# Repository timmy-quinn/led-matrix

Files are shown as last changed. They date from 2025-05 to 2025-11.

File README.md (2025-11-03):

# LED Matrix

A simple 8 by 8 LED matrix made from easy-to-find Neopixel LED strips, 
adhered to a laser-cut baseboard, and mounted in a 3D printed case. 

Control is provided by an ESP32 microcontroller. Code written in the 
Arduino IDE. Several demos can be found in [01_demos](01_demos).  

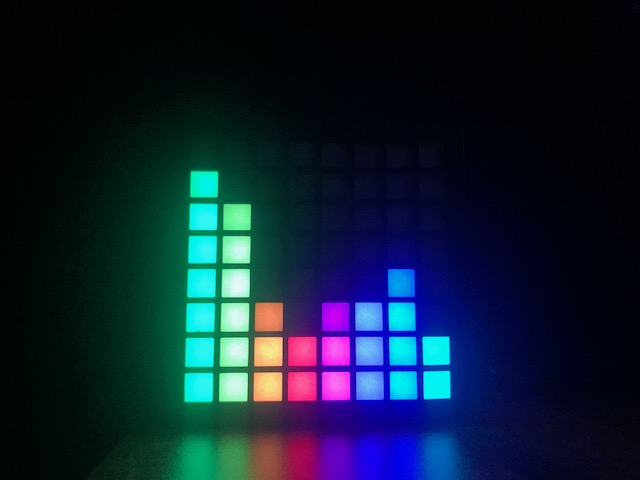
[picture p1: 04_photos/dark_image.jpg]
Music visualizer in the dark
  
*LED-matrix v1.0*

### Materials
- 1 x ESP32 Devkit V1
- 1 x MAX9814 Module
- 1 x WS2812 LED Strip (64 LEDs, 60 Pixel/meter)
- 1 x 1/16th inch wood board (at least 5"x5") 
- 8 x M2 heat-set threaded inserts
- 4 x M3 heat-set threaded inserts
- 4 x M2 x 4mm screws 
- 4 x M2 x 6mm screws
- 4 x M3 x 6mm screws
- 4 x 6mm x 2mm neodymium magnets 
- 1 x Parchment paper or other thin light diffuser
- 1 x 4cm x 6cm universal proto-board
- 1 x 5 pin 2.54mm female header 
- 2 x 20 pin 2.54mm female header
- 1 x JST Female Connector
- 1 x JST Male Connector
- 1 x USB-A to micro-USB type B cable (with data lines)
 
##### Additional requirements 
- 3D printer
- Soldering iron
- Solder
- Super glue
- Hot glue

### Assembly instructions
_More photos to come!_

1. Print the base, cover and back. STL files can be found in [02_mechanical](02_mechanical)
2. Using a soldering iron, insert the 4 M3 heat-set inserts into the outer 
threaded insert holes. Insert the 8 M2 heat-set inserts into the remaining 
holes.  
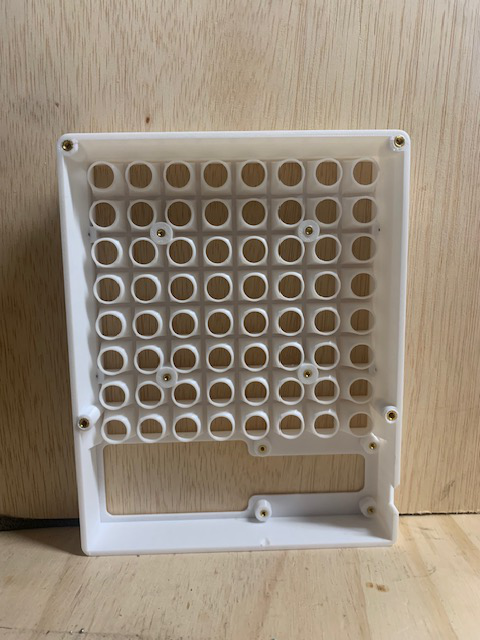
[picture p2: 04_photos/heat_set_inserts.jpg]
Heat set inserts
  
3. Cut out the LED board, with dimensions matching those in the CAD file, 
or use a laser cutter. 
4. Cut the LED strip into sections of 8, cutting down the center of the 
copper pads. 
5. Use the silicone wire to solder the individual LED strips. Make sure 
the wire is the length of the LED board, plus perhaps an extra inch. Make 
sure that the DOUT pad of each LED strip connects the DIN pad of the 
next strip. DO NOT connect a DIN pad to DIN, or a DOUT pad to DOUT.  
6. Attach the LEDs to the board, by removing the thin plastic backing and 
attaching them to the board, using the adhesive on the strip. Then use 
little touches of hot glue around the edges of the board, to prevent the 
LED strip from peeling off, and to cover the exposed wire and copper pads. 
7. To the last LED strip, solder on a JST connector. 
8. Screw the LED board to the 3-d printed base using M2 screws.   
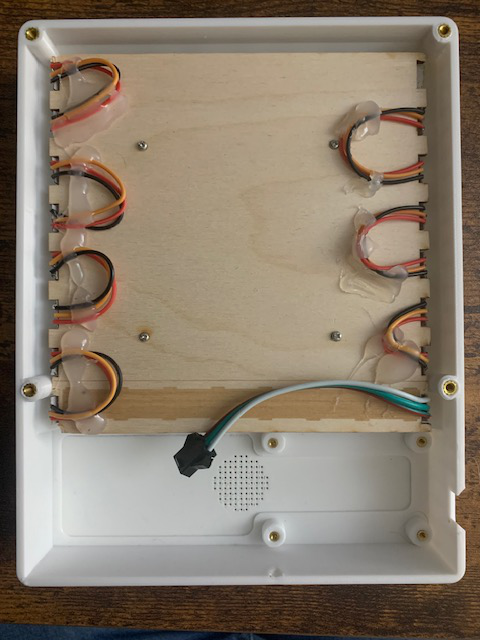
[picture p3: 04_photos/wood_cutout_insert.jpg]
Board attached to base

9. Solder 18 pin female header pins to the proto board. For the microphone, 
add a 5 pin female header pin.
10. Solder a JST connector to the proto-board. (Must be able to connect 
to the corresponding connector attached to the LED strip). Connect 5v to 
the ESP32 VIN pin. Connect ground to GND. Connect DIN to pin D13 (At least 
if you want to be consistent with the demo code. 
11. Solder connections for the MAX9814 header pin. Make sure that V+ is 
connected to the ESP32 3v3 pin, GND is connected to GND, and to be 
consistent with the demo code, connect Out to D32, G (gain) to D5, and AR 
to D22. 
12. Screw the proto-board to case. Insert the ESP32 board into the female 
header pins. Insert the MAX9814 to the corresponding header pins. 
13. Connect the JST connector from the proto board to the LED strips. 
14. Super glue magnets to the exterior of the case, and the interior of the cover.  
Ensure that the magnets are orientated such that when the cover is placed 
onto the case, the magnets attract each other and do not repel each other. 
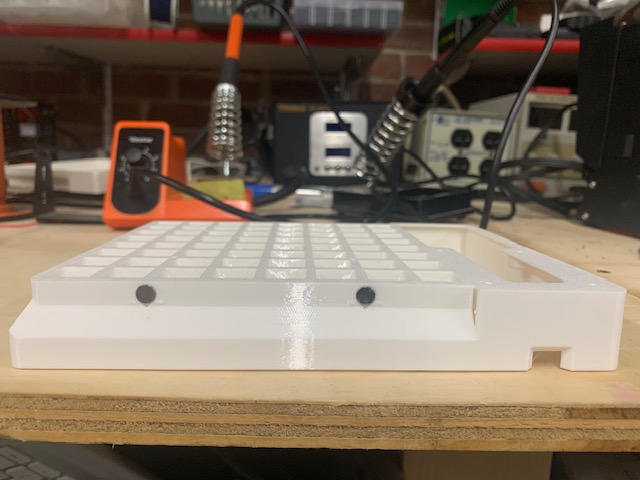
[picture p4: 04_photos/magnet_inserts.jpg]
Magnets inserted into exterior
  
15. Cut a strip of your parchment paper or other diffuser material, using 
the front of the base as a guide. You can leave a little room around the
edges to make sure that the diffuser material covers the entire grid case.   
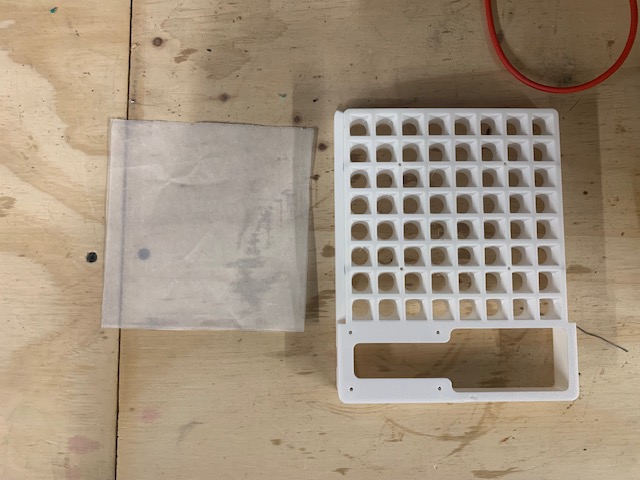
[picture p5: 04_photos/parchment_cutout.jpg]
Diffuser cutout
  
16. Place the diffuser on the base, then put the cover over it.  
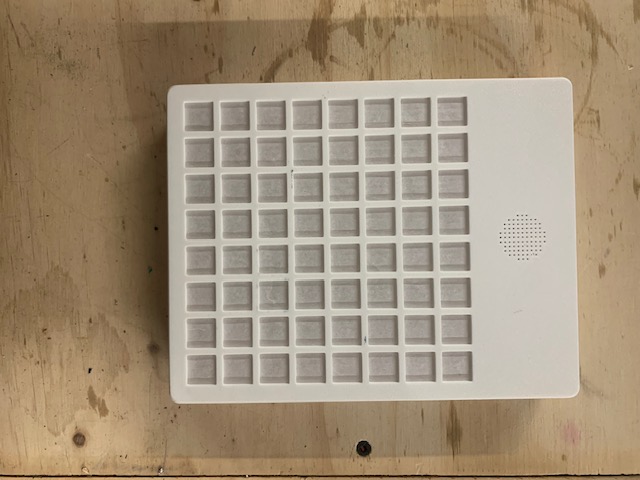
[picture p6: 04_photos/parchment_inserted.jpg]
Diffuser inserted
  
17. Screw the back to the case using M3 screws.     
edges to make sure that the diffuser material covers the entire grid case. 
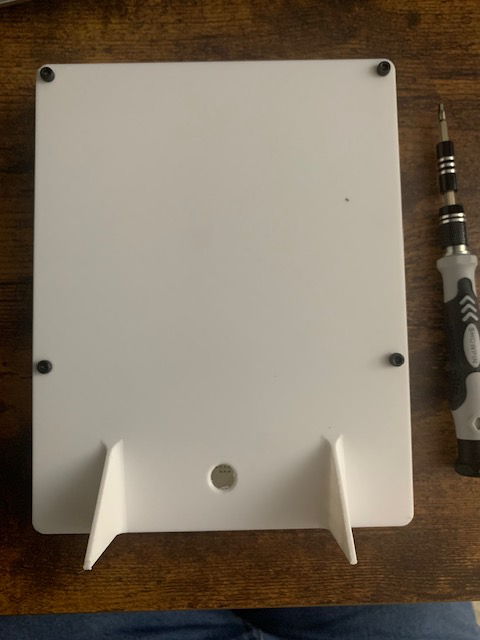
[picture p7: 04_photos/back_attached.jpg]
back attached
  

*And now you're done! Upload one of the demos to the ESP32 to verify the board.*   
  
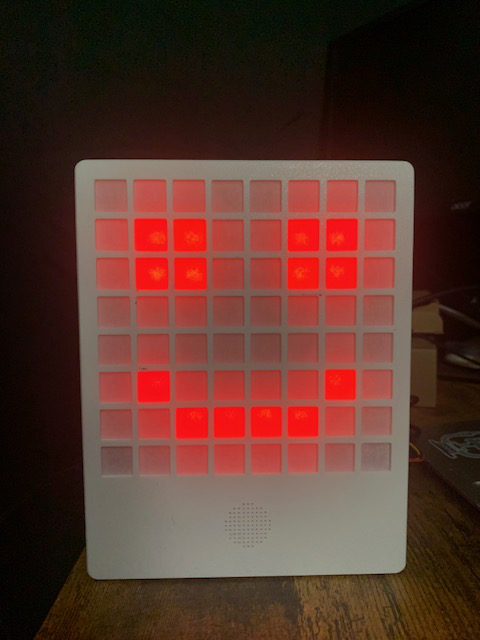
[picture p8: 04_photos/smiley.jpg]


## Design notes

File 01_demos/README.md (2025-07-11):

# Code Demos
These demos provide a range of basic functionality for your LED matrix. Ranging from simply turning on LEDs, to an FFT-based music visualizer and 
displaying simple animations. Currently all of these demos are written 
using the Arduion IDE. To program your board you will therefor need to 
download a few things.  

## Requirements
- [Arduino IDE](https://docs.arduino.cc/software/ide-v2/tutorials/getting-started/ide-v2-downloading-and-installing/)
- [ESP32 Board support package](https://docs.espressif.com/projects/arduino-esp32/en/latest/installing.html)
- [Arduino FFT library](https://github.com/kosme/arduinoFFT)
- [Adafruit NeoPixel library](https://github.com/adafruit/Adafruit_NeoPixel)

*For the multi mode example, you will also need the [Arduino Audio Tools library](https://github.com/pschatzmann/arduino-audio-tools) which cannot be installed through the Arduino Library manager, but rather through git or by downloading the zip*

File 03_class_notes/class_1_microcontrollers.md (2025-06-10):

# Microcontroller Basics

## ESP32 
### Overview  

The ESP32 is a **microcontroller**. A microcontroller a small programmable 
computer chip which interacts with the outside world through a set of input 
and output pins. All a microcontroller does is take some inputs, performs 
some processing, and controls some outputs.  

The seemingly simple capabilities of a microcontroller in fact enable it to 
perform a wide range of functions. You can find microcontrollers in 
everything around you, from headphones, to satellites, to cars to 
3d-printers. The very same ESP32 chip we're going to be using is very popular 
in smart devices, so if you have wifi-controlled lights, or a thermostat 
you can adjust from your phone, you may already have an ESP32 in your home. 

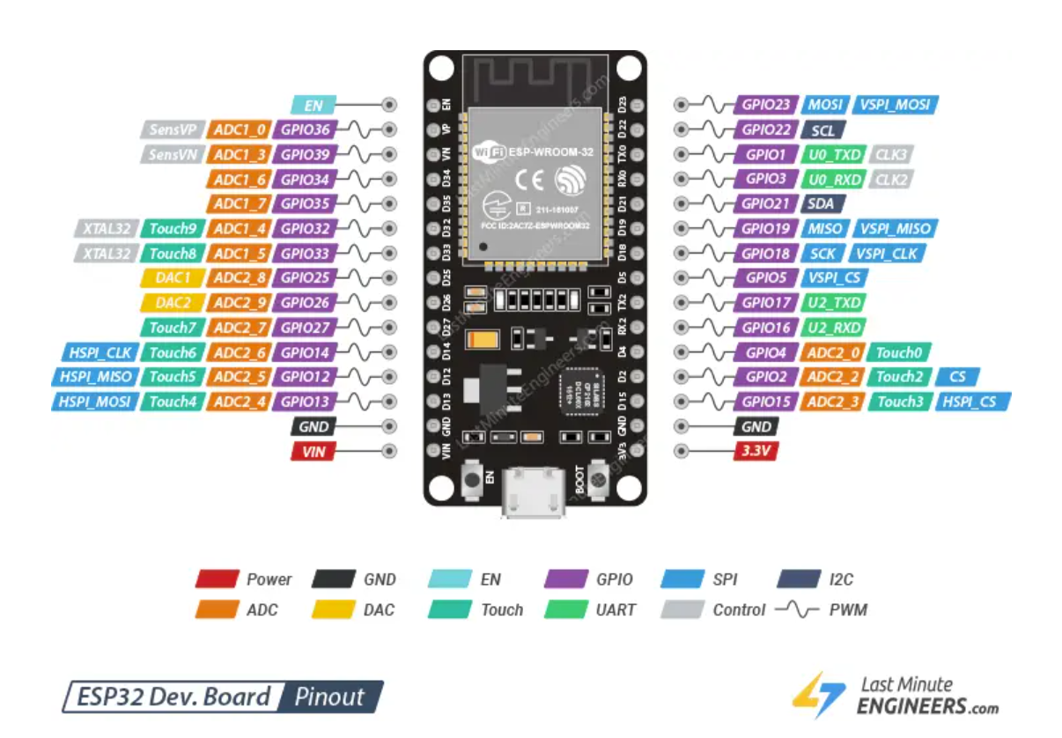
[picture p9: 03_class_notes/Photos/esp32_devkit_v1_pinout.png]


In all of these devices, the fundamental working principle is the same. 
Get data from input pins. Perform some processing. Control the output pins. 

For our project, the input is going to be a microphone, and the output is 
going to be an RGB LED grid. But there are many other options to choose 
from.   
  
#### Inputs and outputs
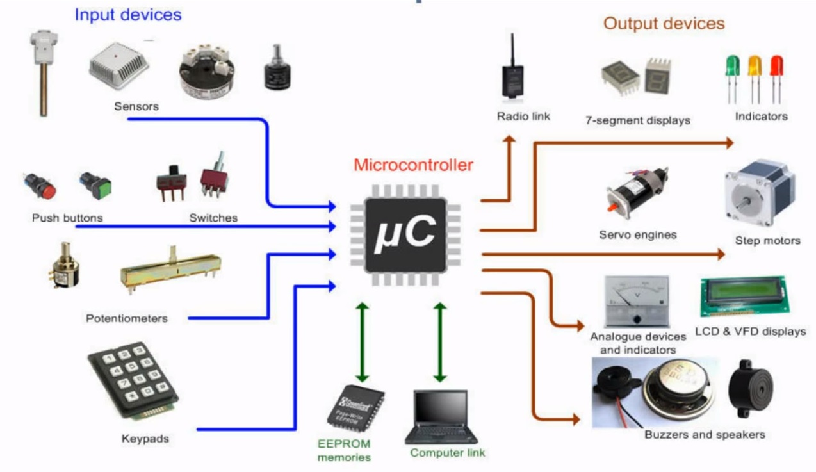
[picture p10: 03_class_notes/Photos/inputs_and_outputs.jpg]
Inputs and outputs


## Setup

1. Download the Arduino IDE [here](https://www.arduino.cc/en/software/)
2. Follow these [instructions](https://docs.espressif.com/projects/arduino-esp32/en/latest/installing.html) 
to set up your ESP32 board. 
  
## Programming your microcontroller 
### Blinky 
When getting started with a new devboard, microcontroller, or project, you're 
almost always going to want to write a blinky program. This is a simple way 
to make sure that your board works, that you know how to upload code to your
board, and that you can use its basic features. 

For us, this will also be a great opportunity to learn about some fundamental 
programming concepts.  

```
// Blinky example 

int LED = 2; 

// Runs once when ESP32 is powered on 
void setup() {
  // Set pin mode
  pinMode(LED,OUTPUT);
}

// Runs in a continuous loop after setup()
void loop() {
  delay(500); // Delays for 500 milliseconds (1/2 second)
  digitalWrite(LED, HIGH);
  delay(500);
  digitalWrite(LED, LOW);
}

```
### Hello world  
Another common test program is the hello world. In fact, when learning a 
new programming language, you're going to write a hello world program
before anything else. 

```
void setup() {
  // Create a serial connection
  // This will enable us to send data 
  // From our microcontroller to our 
  // computer one bit at a time. 
  // 115200 is the speed at which we can
  // send data. This is called the baud 
  // rate and it is measured in bits per
  // second. 
  Serial.begin(115200); 
}

void loop() {
  // Send a string of characters to 
  // our computer. 
  Serial.println("Hello World"); 
  delay(3000); 
}

```
After you upload your code to your microcontroller, click the Serial Monitor 
button in the upper right corner of the Arduino IDE. Make sure the port matches
the port your ESP32 is connected to. Make sure the baud rate matches the rate the ESP32 is set to. You should see the words *Hello World* being printed out 
repeatedly.  

> :memo: **Challenge**  
> Modify the above code to send a message of your choice!    

### Programing basics: What is code?  
  
The snippet shown above is an example of C++ code. But what you see above 
is not actually what is uploaded to our ESP32. 

### Building blocks of a program
 
#### Building Block: Variables
Variables are the way we store information in a program. There are few 
different variable types in C++, which are defined by specific keywords.  

Here are some of the more common types we will encounter in this class. 
  
- <span style="color:teal">int</span>: 
stores whole numbers, typically between -2,147,483,648 to 2,147,483,647
- <span style="color:teal">float</span>: 
stores decimal values, between -3.4^38 to -3.4^38. 
- <span style="color:teal">bool</span>: 
represents either true or false, (1 or 0). bool stands for boolean
  
Now, here we can get to the fun part and can play around with our newfound 
understanding of variables. 

*Example*  

We can perform basic mathematic operations on our variables as well. 
```
void loop() {
  int a = 100; 
  Serial.print("Original: "); 
  Serial.println(a); 

  a = a + 2; 
  Serial.print("Plus 2: "); 
  Serial.println(a); 

  a = a - 1; 
  Serial.print("Minus 1: "); 
  Serial.println(a); 

  a = a * 4; 
  Serial.print("Times 4: "); 
  Serial.println(a); 

  a = a / 2; 
  Serial.print("Divide 2: "); 
  Serial.println(a); 

  Serial.println(); 
  
  delay(5000);
}
```

#### Building Block: Functions 

So it turns out that we've already used functions. ````setup()````, 
````loop()````, ````Serial.println()```` and ````Serial.print()```` are all 
functions. 
  
What is a function, and why do we use it? A function is a reusable block of code 
which performs a specific task. This is super useful in programming. Oftentimes
we want to perform the same task in many different contexts. We can write 
functions which take certain inputs, and then perform some operations on those 
inputs to get a result. 

*Example*
```
int add(int a, int b) {
  return a + b; 
}

void loop() {
  int sum = add(a, b); 
  Serial.print("Function result:");
  Serial.println(sum); 
  delay(10000); 
}
```
> :memo: **Challenge**  
> Write a function that takes an integer as an argument and returns the square of 
> that integer.   
> **Bonus**  
> In the function, print the result in this format: ```` var squared equals result````  

Something else to note about a function is that variables declared within a 
function cannot be accessed outside of that function. 

#### Building Blocks: if else  
We don't always want out program to do the same thing every time. We want our 
little computer to be able to make some decisions. We want to be able to turn 
on a light if a button is pressed. We want to be able to stop a motor if a 
robotic arm has reached the correct position. 
  
How are we going to do this? This is where if else statements come in. These 
simple statements when coupled with other code can enable some very complex, 
intelligent behavior.  
```
void print_greater_than_equal(int test, int threshold) {
  if(test >= threshold) {
    print("Success!!!"); 
  }
  else {
    print("Failure ");
  }
}

void print_comparison(int a, int b) {
  if(a > b) {
    Serial.println("Greater than"); 
  }
  else if(a < b) {
    Serial.println("Less than"); 
  }
  else {
    Serial.println("Equal"); 
  }
}

void loop() {
  int threshold = 10; 

  print_comparison(1, threshold); 
  print_comparison(12, threshold); 
  print_comparison(threshold, threshold); 
  print_comparison(threshold - 1, threshold); 

  Serial.println();
  Serial.println("Greater than equal function"); 
  print_greater_than_equal(threshold, threshold);  
  print_greater_than_equal(threshold - 1, threshold); 

}
```

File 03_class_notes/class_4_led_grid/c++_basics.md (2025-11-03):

# Programming LED Matrix

## Basic C++
### Basic data types
**integers:**
```c++
int myInt = 16;
```
Integers store whole numbers between -2,147,483,648 to 2,147,483,647

**floating-point numbers:**
```c++
float myFloat = 10.11;
float myFloat = 10.0;
```
Floating-point numbers store decimal values  1.17549435×10^−38 to 3.4028235×10^38

**boolean:**
```c++ 
bool myBool = true;
bool myOtherBool = false;
```
Booleans store either true or false. 

**arrays:**
```c++
bool boolArray[10];
int intArray[3];
float floatArray[4] = {1, 2, 3, 4};
```
Arrays are data structures which store a fixed-size collection of elements of
the same data type. You can access elements of the same data type as shown below.
```c++
// intArray = {0, 0, 0};
intArray[0] = 1;
intArray[1] = 10,000;
intArray[2] = 12;
// now intArray = {1, 10,000, 12};
```
Note, arrays are zero-indexed.

### Basic operators
```c++
int a;
a = 10 + 1;
a = 10 - 1;
a = 10 * 1;
a = 21 / 5; // Since a is an int, remainder is ignored, so a = 4 
```
**modulus operator:**
When dividing integers, the remainder is ignored. Modulus operator is used to
return remainder.
```c++
int a;
a = 21 % 2; // remainder is 1
a = 20 % 2; // remainder is 0
```
This will be useful for our project.

### Control flow
**if:**
```c++
int x = 10;
if(x == 10) {
    Serial.println("Equal");
}
```

**else if, else**: 
We can add on to if statements with else if and else statements.
```c++
int x = 10;
if (x > 10) {
    Serial.println("Greater");
}
else if (x == 10) {
    Serial.println("Equal");
}
else {
    Serial.println("Less");
}
```

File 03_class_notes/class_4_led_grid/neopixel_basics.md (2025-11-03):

# Adafruit Neopixel library basics

## Basic usage
```c++
// We must include the Adafruit NeoPixel library
#include <Adafruit_NeoPixel.h>

// Variables describing the LED grid 
int PIXEL_COLS_VISIBLE = 8;
int PIXEL_COLS_HIDDEN = 9; 
int PIXEL_COLS_TOTAL = PIXEL_COLS_VISIBLE + PIXEL_COLS_HIDDEN;
int PIXEL_ROWS = 8;
int PIXEL_COUNT = PIXEL_ROWS * PIXEL_COLS_TOTAL; 
int PIXEL_PIN = 13; 

// initialize our neopixels
Adafruit_NeoPixel pixels(PIXEL_COUNT, PIXEL_PIN, NEO_GRB + NEO_KHZ800);

void setup() {
    // Set the brightness. 
    // We can set the maximum brightness of our LEDs. 
    // We only need to set this once
    pixels.setBrightness(15);

    // Initialize the pixels. Only needs to be done once
    pixels.begin();

    // Our pixels are RGB. We can set the value of each LED in the pixels. 
    // The combination will determine the color. 
    int red = 0;
    int green = 0;
    int blue = 255;
    
    pixels.setPixelColor(0, red, green, blue);
    pixels.setPixelColor(1, red, green, blue);
    pixels.setPixelColor(2, red, green, blue);
    
    // Once we've set our LED colors to our desired values, an extra step is 
    // required to get our NeoPixels to actually show those colors
    // Must be called every time we want to change the LEDs
    pixels.show();
}
```

To set all of the pixels, we can also do this: 
```c++
    // Using a for loop, loop over all of the pixels
    for(int pix = 0; pix < PIXEL_COUNT; pix++) {
      pixels.setPixelColor(pix, red, green, blue);
    }
```

We can also use the ```Adafruit_NeoPixel.Color()``` function to obtain the RGB 
value in a single integer.
```c++
    int color = pixels.Color(red, green, blue);
    // Using a for loop, loop over all of the pixels
    for(int pix = 0; pix < PIXEL_COUNT; pix++) {
      pixels.setPixelColor(pix, color); // Just pass in the color to the led matrix
    }
```

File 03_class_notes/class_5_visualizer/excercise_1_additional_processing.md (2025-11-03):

```c++
#include <arduinoFFT.h>
#include <Adafruit_NeoPixel.h>

///////////////////////////////////////////////////////////////////////////////////////////////////////
// Microphone
///////////////////////////////////////////////////////////////////////////////////////////////////////
// Variables describing the LED grid 
int PIXEL_COLS_VISIBLE = 8;
int PIXEL_COLS_HIDDEN = 9; 
int PIXEL_COLS_TOTAL = PIXEL_COLS_VISIBLE + PIXEL_COLS_HIDDEN;
int PIXEL_ROWS = 8;
int PIXEL_COUNT = PIXEL_ROWS * PIXEL_COLS_TOTAL; 
int PIXEL_PIN = 13; 

// initialize our neopixels
Adafruit_NeoPixel pixels(PIXEL_COUNT, PIXEL_PIN, NEO_GRB + NEO_KHZ800);

void setGridPixel(int row, int col, int color) {
    /*
    * Write a function that takes in a row and column, then sets the 
    * corresponding pixel.
    */
    int pixel;
    pixel = row * PIXEL_COLS_TOTAL + col;
    pixels.setPixelColor(pixel, color);
    
}

void setGridColumn(int col, int height, int color) {
    /*
    * Write a function that takes in a column number and height, then sets the 
    * corresponding pixels.
    */
    for(int i = 0; i < height; i++) {
      setGridPixel(i, col, color);
    }

    for(int i = height; i < PIXEL_ROWS; i++) {
      setGridPixel(i, col, 0);
    }
}

int getColumnColor(int col) {
    /*
    * Write a function to get the column color
    */
    int maxHue = 65535;
    int maxSaturation = 255;
    int maxValue = 255;

    // The hue increases in steps across the columns
    int hue = col *(maxHue /PIXEL_COLS_VISIBLE);
    return pixels.ColorHSV(hue, maxSaturation, maxValue); 
}

void setGridColumnWithColor(int col, int height) {
    int color = getColumnColor(col);
    setGridColumn(col, height, color);
}

void setupPixels() {
    // Set the brightness. 
    // We can set the maximum brightness of our LEDs. 
    // We only need to set this once
    pixels.setBrightness(15);

    // Initialize the pixels. Only needs to be done once
    pixels.begin();
}

///////////////////////////////////////////////////////////////////////////////////////////////////////
// Microphone
///////////////////////////////////////////////////////////////////////////////////////////////////////
// Micorphone pins
const int MIC_PIN = 32; 
const int GAIN_PIN = 5; 

const int SAMPLING_FREQUENCY = 20000;  
const int SAMPLING_PERIOD_uS = (1.0 / SAMPLING_FREQUENCY) * 1000000; // Sampling period in microseconds
const int SAMPLE_COUNT = 1024; // Must be a power of two
const int USABLE_MAGNITUDE_COUNT = SAMPLE_COUNT / 2; 

// Declare Arduino FFT Object
double vReal[SAMPLE_COUNT];
double vImag[SAMPLE_COUNT];
ArduinoFFT<double> FFT = ArduinoFFT<double>(vReal, vImag, SAMPLE_COUNT, SAMPLING_FREQUENCY);

const int AVERAGE_COUNT = 8;
double avgBins[AVERAGE_COUNT];

// Calculate the fast fourier transform
void calculateFFT() {
  int sampleStartTime;
  for(int i = 0; i < SAMPLE_COUNT; i++) {
    sampleStartTime = micros();
    vReal[i] = analogRead(MIC_PIN);
    vImag[i] = 0; 
    while(micros() - sampleStartTime < SAMPLING_PERIOD_uS) {/*wait*/ }
  }
  FFT.dcRemoval();
  FFT.windowing(FFT_WIN_TYP_HAMMING, FFT_FORWARD);
  FFT.compute(FFT_FORWARD); 
  FFT.complexToMagnitude();

}

void averageBins() {
  const int avgBinSize = USABLE_MAGNITUDE_COUNT / AVERAGE_COUNT;
  for(int i = 0; i < AVERAGE_COUNT; i++) {
    avgBins[i] = 0;
    for(size_t j = 0; j < avgBinSize; j++) {
      avgBins[i] += vReal[i * avgBinSize + 1];
    }
    avgBins[i] /= avgBinSize;
  }
}

void printFFT() {
  for(int i = 0; i < USABLE_MAGNITUDE_COUNT; i++) {
    Serial.print(vReal[i]);
    Serial.print(", ");
  }
  Serial.println("");
}

void printAverage() {
  for(int i = 0; i < AVERAGE_COUNT; i++) {
    Serial.print(avgBins[i]);
    Serial.print(", ");
  }
  Serial.println("");
}

void setupMic() {
  // Initialize Serial communication (UART peripheral)
  Serial.begin(115200); 
  // Configure the microphone pin as an input
  pinMode(MIC_PIN, INPUT);
}

void setup() {
  setupMic();
  setupPixels();
}

void loop() {
  calculateFFT();
  averageBins();
  displayFFT();
}

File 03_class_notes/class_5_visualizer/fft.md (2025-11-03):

# Fast Fourier Transform

```c++
#include <arduinoFFT.h>
// Microphone pins
const int MIC_PIN = 32; 
const int GAIN_PIN = 5; 
const int SAMPLING_FREQUENCY = 20000;  
const int SAMPLING_PERIOD_uS = (1.0 / SAMPLING_FREQUENCY) * 1000000; // Sampling period in microseconds
const int SAMPLE_COUNT = 8; // Must be a power of two
const int USABLE_MAGNITUDE_COUNT = SAMPLE_COUNT / 2; 

// Declare Arduino FFT Object
double vReal[SAMPLE_COUNT];
double vImag[SAMPLE_COUNT];
ArduinoFFT<double> FFT = ArduinoFFT<double>(vReal, vImag, SAMPLE_COUNT, SAMPLING_FREQUENCY);

// Calculate the fast fourier transform
void gatherSamples() {
    // Gather samples
    // We collect SAMPLE_COUNT number of samples. Between samples we pause 
    // for  
    int sampleStartTime;
    for(int i = 0; i < SAMPLE_COUNT; i++) {
        sampleStartTime = micros();
        // Here, we read from the analog input pin connected to the 
        // Microphone
        vReal[i] = analogRead(MIC_PIN);
        vImag[i] = 0; 
        // Wait between samples until the sampling period has elapsed
        while(micros() - sampleStartTime < SAMPLING_PERIOD_uS) {/*wait*/ }
    }
}
    
void calculateFFT() {
    // Utilise the arduinoFFT library to actually calculate the FFT 
    // Consult the library docs here 
    // https://docs.arduino.cc/libraries/arduinofft/
    FFT.dcRemoval();
    FFT.windowing(FFT_WIN_TYP_HAMMING, FFT_FORWARD);
    FFT.compute(FFT_FORWARD); 
    FFT.complexToMagnitude();
}

void printFFT() {
    static double maxFFT = 500;
    for(int i = 0; i < USABLE_MAGNITUDE_COUNT; i++) {
        if(vReal[i] > maxFFT) {
          maxFFT = vReal[i];
        }
        Serial.print(vReal[i]);
        Serial.print(", ");
    }
    // Print a ceiling. This will prevent the serial plotter from 
    // jumping around so much.
    Serial.println(maxFFT);
    // Or just print a new line
    // Serial.println();
}

void setupMic() {
    // Configure the microphone pin as an input
    pinMode(MIC_PIN, INPUT);
}

void setup() {
    Serial.begin(115200); 
    setupMic();
}

void loop() {
    gatherSamples();
    calculateFFT();
    printFFT(); 
}

```
### Experiment: 
Play around with changing the number of samples taken.

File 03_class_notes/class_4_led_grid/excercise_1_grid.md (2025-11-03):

# Set Grid Pixels 
We want to be able to access pixels in the grid one by one. We don't want to 
have to calculate each time which specific pixel in the strip corresponds to 
that position in the grid.

**Write a function that takes a row and column, then sets a specific pixel on 
the grid.**

### Template

```c++
// We must include the Adafruit NeoPixel library
#include <Adafruit_NeoPixel.h>

// Variables describing the LED grid 
int PIXEL_COLS_VISIBLE = 8;
int PIXEL_COLS_HIDDEN = 9; 
int PIXEL_COLS_TOTAL = PIXEL_COLS_VISIBLE + PIXEL_COLS_HIDDEN;
int PIXEL_ROWS = 8;
int PIXEL_COUNT = PIXEL_ROWS * PIXEL_COLS_TOTAL; 
int PIXEL_PIN = 13; 

// initialize our neopixels
Adafruit_NeoPixel pixels(PIXEL_COUNT, PIXEL_PIN, NEO_GRB + NEO_KHZ800);

void setGridPixel(int row, int col, int color) {
  /*
  * Write a function that takes in a row and column, then sets the 
  * corresponding pixel.
  */
}

void setup() {
    // Set the brightness. 
    // We can set the maximum brightness of our LEDs. 
    // We only need to set this once
    pixels.setBrightness(15);

    // Initialize the pixels. Only needs to be done once
    pixels.begin();

}

void loop() {
    int red = 0;
    int blue = 0;
    int green = 255;
    int color = pixels.Color(red, green, blue);

    // Our pixels are RGB. We can set the value of each LED in the pixels. 
    // The combination will determine the color. 
    for(int row = 0; row < PIXEL_ROWS; row++) {
        for(int col = 0; col < PIXEL_COLS_VISIBLE; col++) {
            setGridPixel(row, col, color);
            delay(300);
            pixels.show();
        }
    }
}

```
  
### Tips: 
Think of an algorithm that will translate two numbers, the row, and the column, 
into the pixel number. 
Start out simply. Start with just the first row and write a function that can 
take in a row and column, and accurately control the first row. Then begin 
thinking about the second. 
Don't worry about the LEDs on the back which are not visible. Focus on just the 
visible LEDs.

### Row, Col to Pixel Number  
| |Col 0| Col 1 | Col 2 | Col 3 | Col 4 | Col 5 | Col 6 | Col 7 |
|---|---|---|---|---|---|---|---|---|
|**Row 7**|119|120|121|122|123|124|125|126|
|**Row 6**|102|103|104|105|106|107|108|109|
|**Row 5**|85 |86 |87 |88 |89 |90 |91 |92 |
|**Row 4**|68 |69 |70 |71 |72 |73 |74 |75 |
|**Row 3**|51 |52 |53 |54 |55 |56 |57 |58 |
|**Row 2**|34 |35 |36 |37 |38 |39 |40 |41 |
|**Row 1**|17 |18 |19 |20 |21 |22 |23 |24 |
|**Row 0**| 0 | 1 | 2 | 3 | 4 | 5 | 6 | 7 |

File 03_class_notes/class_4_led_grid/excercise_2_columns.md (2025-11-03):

# Set Columns 
In our music visualizer, each column of our LED grid is going to represent 
the how much a particular frequency range is in our audio signal.

LED Matrix

**Excercise: Write a function to set the height of each column.**

### Template
```c++
// We must include the Adafruit NeoPixel library
#include <Adafruit_NeoPixel.h>

// Variables describing the LED grid 
int PIXEL_COLS_VISIBLE = 8;
int PIXEL_COLS_HIDDEN = 9; 
int PIXEL_COLS_TOTAL = PIXEL_COLS_VISIBLE + PIXEL_COLS_HIDDEN;
int PIXEL_ROWS = 8;
int PIXEL_COUNT = PIXEL_ROWS * PIXEL_COLS_TOTAL; 
int PIXEL_PIN = 13; 

// initialize our neopixels
Adafruit_NeoPixel pixels(PIXEL_COUNT, PIXEL_PIN, NEO_GRB + NEO_KHZ800);

void setGridPixel(int row, int col, int color) {
    /*
    * Write a function that takes in a row and column, then sets the 
    * corresponding pixel.
    */
}

void setGridColumn(int col, int height, int color) {
    /*
    * Write a function that takes in a column number and height, then sets the 
    * corresponding pixels.
    */
}

void setup() {
    // Set the brightness. 
    // We can set the maximum brightness of our LEDs. 
    // We only need to set this once
    pixels.setBrightness(15);

    // Initialize the pixels. Only needs to be done once
    pixels.begin();
}

void loop() {
    int red = 255;
    int blue = 0; 
    int green = 0;

    int color = pixels.Color(red, green, blue);
    int height = 0;
    // Our pixels are RGB. We can set the value of each LED in the pixels. 
    // The combination will determine the color. 
    for(int col = 0; col < PIXEL_COLS_VISIBLE; col++) {
        height = col + 1;
        setGridColumn(col, height, color);
    }
    pixels.show();
    delay(1000);
    for(int col = 0; col < PIXEL_COLS_VISIBLE; col++) {
        height = PIXEL_COLS_VISIBLE - col;
        setGridColumn(col, height, color);
    }
    pixels.show();
    delay(1000);

}
```

### Tips
1. Use setGridPixel() function that you wrote in the previous excercise.
2. Remember for each column that you must clear the unused pixels. 
3. Setting the pixel colors to all zero will turn off the pixel.
4. Think about how you can use a for loop to loop over all the pixels in a column.

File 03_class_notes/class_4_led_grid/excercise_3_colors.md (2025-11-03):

# Set Columns 
To make our music visualizer look nice and pretty, we add colors to each column 
of the LED music visualizer. There are many ways to do this. Feel free to set 
it up however looks best to you.

LED Matrix

**Excercise: Write a function to get the color of each column, then use the 
functions you wrote in the previous excercises to display those colors**

### Template
```c++
// We must include the Adafruit NeoPixel library
#include <Adafruit_NeoPixel.h>

// Variables describing the LED grid 
int PIXEL_COLS_VISIBLE = 8;
int PIXEL_COLS_HIDDEN = 9; 
int PIXEL_COLS_TOTAL = PIXEL_COLS_VISIBLE + PIXEL_COLS_HIDDEN;
int PIXEL_ROWS = 8;
int PIXEL_COUNT = PIXEL_ROWS * PIXEL_COLS_TOTAL; 
int PIXEL_PIN = 13; 

// initialize our neopixels
Adafruit_NeoPixel pixels(PIXEL_COUNT, PIXEL_PIN, NEO_GRB + NEO_KHZ800);

void setGridPixel(int row, int col, int color) {
    /*
    * Write a function that takes in a row and column, then sets the 
    * corresponding pixel.
    */
}

void setGridColumn(int col, int height, int color) {
    /*
    * Write a function that takes in a column number and height, then sets the 
    * corresponding pixels.
    */
}

int getColumnColor(int col) {
    /*
    * Write a function to get the column color
    */
}

void setGridColumnWithColor(int col, int height) {
    int color = getColumnColor(col);
    setGridColumn(col, height, color);
}

void setup() {
    // Set the brightness. 
    // We can set the maximum brightness of our LEDs. 
    // We only need to set this once
    pixels.setBrightness(15);

    // Initialize the pixels. Only needs to be done once
    pixels.begin();
}

void loop() {
    int height = 0;
    // Our pixels are RGB. We can set the value of each LED in the pixels. 
    // The combination will determine the color. 
    for(int col = 0; col < PIXEL_COLS_VISIBLE; col++) {
        height = col + 1;
        setGridColumnWithColor(col, height);
        delay(50);
        pixels.show();
    }
    delay(1000);

    for(int col = PIXEL_COLS_VISIBLE - 1; col >= 0; col--) {
        height = PIXEL_COLS_VISIBLE - col;
        setGridColumnWithColor(col, height);
        delay(50);
        pixels.show();
    }
    delay(1000);
}```

### Tips
1. Another way to get a pixel color is to use the ````Adafruit_Neopixel.ColorHSV```` function.
It takes 3 arguments, hue, saturation, and value. You can think of hue as the 
color on the color wheel, (red, purple, blue, green, etc.). Saturation is the 
intensity or purity of the color. Value is the brightness.  
The NeoPixel function takes values between 0 and 65535 for the hue. The saturation 
and value are integers between 0 and 255.  
If you increment the hue, you can create a rainbow effect.
More info can be found [here](https://adafruit.github.io/Adafruit_NeoPixel/html/class_adafruit___neo_pixel.html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) 
in the Adafruit_NeoPixel documentation.

2. You may want to consider storing the colors of each column in an array. 
(This can be done as an alternative approach to using the ````ColorHSV```` 
function, or in conjunction with it).

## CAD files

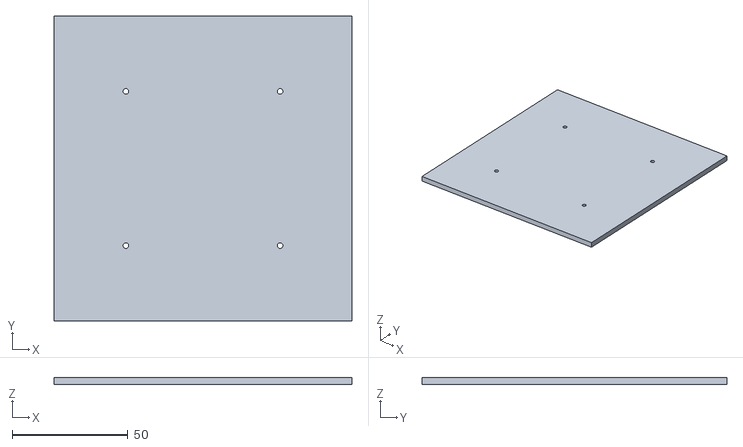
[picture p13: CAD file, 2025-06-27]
02_mechanical/LED board.stl
128.8 x 131.8 x 3.18

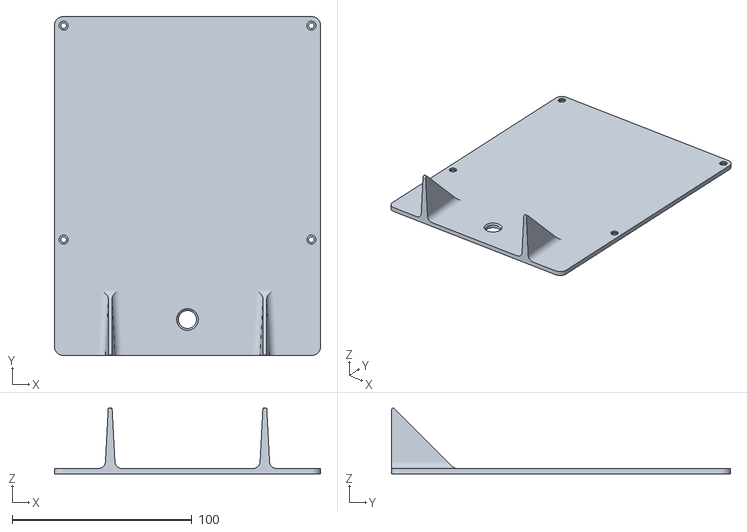
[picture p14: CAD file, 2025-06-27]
02_mechanical/Back.stl
147.9 x 188.4 x 36.6

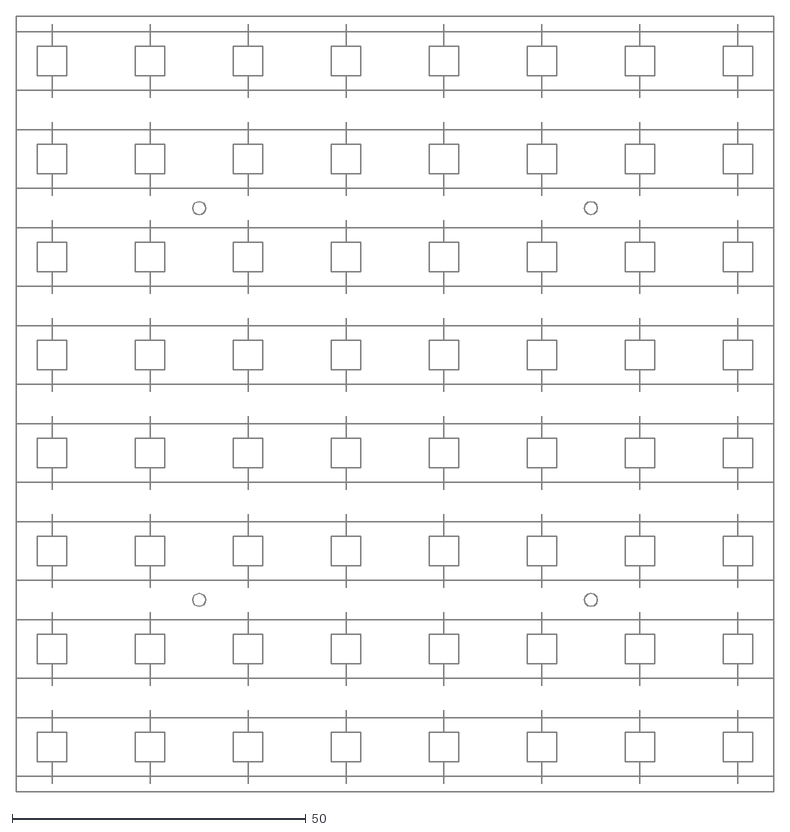
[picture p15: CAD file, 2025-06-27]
02_mechanical/LED board - Guidelines.dxf
128.8 x 131.8

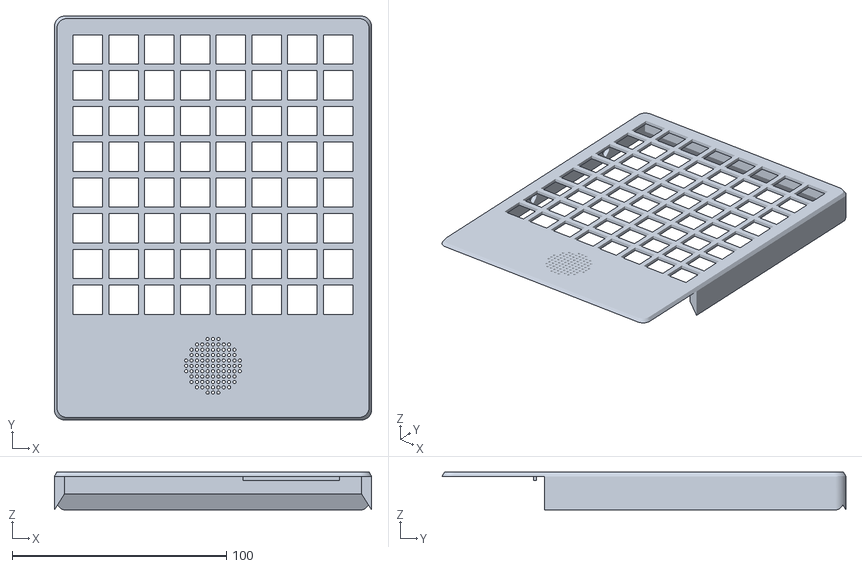
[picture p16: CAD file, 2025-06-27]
02_mechanical/Cover.stl
147.9 x 188.4 x 17.7

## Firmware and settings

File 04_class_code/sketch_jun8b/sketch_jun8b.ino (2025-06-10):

#include <arduinoFFT.h>
#include <Adafruit_NeoPixel.h>
#include <stdint.h>

const int MIC_PIN = 32; 
const int GAIN_PIN = 5; 
const uint32_t SAMPLING_FREQUENCY = 40000;  
const uint32_t SAMPLING_PERIOD_uS = (1.0 / SAMPLING_FREQUENCY) * 1000000; // Sampling period in microseconds
const int SAMPLE_COUNT = 1024; // Muset be a power of two
const int USABLE_MAGNITUDE_COUNT = SAMPLE_COUNT / 2; 


double vReal[SAMPLE_COUNT];  
double vImag[SAMPLE_COUNT];  
ArduinoFFT<double> FFT = ArduinoFFT<double>(vReal, vImag, SAMPLE_COUNT, SAMPLING_FREQUENCY);

// FFT Processing
const double MAGNITUDE_SCALE_FACTOR =35.0; 
const double MAGNITUDE_THRESHOLD = 75.0;

const int PIXEL_COUNT = 64; 
const int PIXEL_PIN = 13; 
const uint8_t PIXEL_BRIGHTNESS = 15; 
static Adafruit_NeoPixel pixels(PIXEL_COUNT, PIXEL_PIN, NEO_GRB + NEO_KHZ800);
const uint16_t PIXEL_ROWS = 8;
const uint16_t PIXEL_COLUMNS = 8;


const size_t BINS_PER_COL = USABLE_MAGNITUDE_COUNT / PIXEL_COLUMNS; 

static double averageMagnitudes[PIXEL_COLUMNS]; 
static double runningAverageMagnitude[PIXEL_COLUMNS]; 
static uint16_t columnHeights[PIXEL_COLUMNS]; 
static uint32_t columnColors[PIXEL_COLUMNS];


static void setArrColor(uint16_t row, uint16_t col, uint32_t color);
void initColumnColors(); 

static void setArrColor(uint16_t row, uint16_t col, uint32_t color) {
  row = min(row, static_cast <uint16_t>(PIXEL_ROWS - 1u)); 
  col = min(col, static_cast <uint16_t>(PIXEL_COLUMNS - 1u));
  
  uint16_t pixel;
  uint16_t corrected_col = (row%2) ? PIXEL_COLUMNS - 1 - col : col; 
  pixel = row * PIXEL_COLUMNS + corrected_col;  

  pixels.setPixelColor(pixel, color); 
}

// Initialize the array which stores the colors for each channel
void initColumnColors() {
  uint16_t hue; 
  for(size_t i = 0; i < PIXEL_COLUMNS; i++) {
    hue = (0xffff/PIXEL_COLUMNS) * i; 
    columnColors[i] = pixels.ColorHSV(hue, 255, 255); 
  }
}


static void runningAverage() {  
  for(uint16_t col = 0; col < PIXEL_COLUMNS; col++) {
    runningAverageMagnitude[col] = (static_cast <int>(averageMagnitudes[col]) + runningAverageMagnitude[col])/ 2; 
  }
}


static void averageBinsToColumns() {
    float diff;
    double avg_mag;
    size_t bin; 

    for(size_t i = 0; i < PIXEL_COLUMNS; i++) {
      avg_mag = 0; 
      for(size_t j = 0; j < BINS_PER_COL; j++) {

        bin = i * BINS_PER_COL + j; 
        if(bin < 2) {
          continue; 
        }
        if(bin > 1024) {
          Serial.println("LESS THAN 1024"); 
        }
        if(vReal[bin] < 0.0) {
          Serial.println("magnitude less than ZERO"); 
        }
        avg_mag += vReal[bin] / BINS_PER_COL; 
      }
      averageMagnitudes[i] = avg_mag; 
    } 
    // for(uint16_t i = 0; i < PIXEL_ROWS; i++) {
    //   Serial.printf("%lf, ", averageMagnitudes[i]); 
    // }
    // Serial.println(); 
}


static uint16_t mapMagnitudeToHeight(int magnitude) {
  uint16_t corrected_magnitude = (magnitude > MAGNITUDE_THRESHOLD) ? magnitude - MAGNITUDE_THRESHOLD : 0; 
  uint16_t height = static_cast <uint16_t>( corrected_magnitude / MAGNITUDE_SCALE_FACTOR);
  // Serial.printf("%u ,", height); 
  return height; 
}


static void displayColumns() {
  uint16_t height; 
  for(uint16_t col = 0; col < PIXEL_COLUMNS; col++) {
    height = mapMagnitudeToHeight(runningAverageMagnitude[col]); 
    for(uint16_t row = 0; row < PIXEL_ROWS; row++) {
      if(row <= height) {
        setArrColor(row, col, columnColors[col]); 
      }
      else {
        setArrColor(row, col, 0);         
      }
    }
  }
  pixels.show();
  Serial.println(); 
}


void displayFFT(){
  averageBinsToColumns(); 
  runningAverage();  
  displayColumns(); 
}


void setup() {
  Serial.begin(115200); 
  pinMode(MIC_PIN, INPUT);
  pixels.setBrightness(PIXEL_BRIGHTNESS);
  pixels.begin(); 
  initColumnColors();
}

void loop() {
  uint32_t sampleStartTime;  
  for(int i = 0; i < SAMPLE_COUNT; i++) {
    sampleStartTime = micros();
    vReal[i] = analogRead(MIC_PIN); 
    vImag[i] = 0; 
    while(micros() - sampleStartTime < SAMPLING_PERIOD_uS) {/*wait*/ }
  }
  // FFT.dcRemoval(); 
  FFT.windowing(FFT_WIN_TYP_HAMMING, FFT_FORWARD); 
  FFT.compute(FFT_FORWARD); 
  FFT.complexToMagnitude(); 
  
  // for(int i = 0; i < MI; i++) {
  //   Serial.print(i); 
  //   Serial.print(": "); 
  //   Serial.println(vReal[i]); 
  //   if(vReal[i] < 0.0) {
  //     Serial.println("NEGATIVE"); 
  //   }
  // }
  // Serial.println();
  // for(uint16_t i = 0; i < PIXEL_ROWS; i++) {
  //   for(uint16_t j = 0; j < PIXEL_COLUMNS; j++) {
  //     setArrColor(i, j, 0xff); 
  //   }
  // // }
  // pixels.show(); 

  displayFFT(); 
}

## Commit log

2025-05-21 Updated to reduce latency for state changes between button presses
2025-05-22 Reorganized and added mechanical designs
    [LED_Matrix_Base.stl, LED_Matrix_Cover.stl, LED_Matrix_backboard.dxf]
2025-06-10 Edit pins and add simplified code for class (#2)
    * refactor fft visualizer code for clarity, and enable configuration of microphone input pin
    * tuning fft visualizer parameters and improving code formating
    * Add code for class
    * Class version of code
    Simplified version of reading audio signal and displaying fourier transform result
2025-06-24 Update class code (#3)
    * reorganized code specifically for class
    * Updated arduino code with logarithmic arrangement of bins, and refined normalization'
    * Tuned and updated led matrix class code
    * Updated class code for basic LED grid
2025-06-27 Add notes (#4)
    * Updated multi mode demo
    * Update README and add CAD files
    * Tuned frequency magnitude offsets and scales
    * Updated README link to demos
    [Back.stl, Cover.stl, LED board - Guidelines.dxf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]
2025-07-11 Tune fft normalization for display parameters (#5)
    * Tune fft normalization parameters
    * Update, refactor, and format code
    * Updated README.md and added photos
    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
2025-11-03 Readme edits (#9)
    * Update README and add some notes
    * Added notes, demos, and excercises for class
    * updated class notes
    * fixed columns and colors demos
    * Update excercise_1_grid.md
    * Update excercise_1_grid.ino
    * removed redundant cache files
    * Updated class notes
    * Updated class code
    [basic_led_grid.ino, excercise_1_fft.ino, excercise_1_grid.ino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]
